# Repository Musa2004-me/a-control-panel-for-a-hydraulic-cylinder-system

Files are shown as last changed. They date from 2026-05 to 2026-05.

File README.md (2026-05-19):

Project Summary 

➢ This project focuses on simulating and operating a control panel for a hydraulic cylinder system. 

➢ The controlling panel manages the extending and retracting a hydraulic piston cylinder with 2 limit switches. 

➢ The primary objective is to understand of the panel's components, their interactions, and the role of hardwiring in its operation. 

https://github.com/user-attachments/assets/3112c67c-48e2-4e45-8f05-624a87322188

https://github.com/user-attachments/assets/3ad71fbe-07a0-4319-b49c-5bb209e37cf8

https://github.com/user-attachments/assets/a876eac6-be53-4f7f-acb0-bc190092581f

Specific Objectives: 
1. Component Identification: identify and understand the function of each 
component, including the hydraulic cylinder, valves, pump, sensors, and 
control logic. 
2. Hardwiring Analysis: Analyse the hardwiring scheme, focusing on the 
connections between components, signal flow, and the role of specific 
wires. 
3. Control Logic Simulation: Simulate the panel's control logic and 
analyse its behaviour. 
4. Real-World Panel Construction: Build a physical control panel that can 
be integrated it with the hydraulic system. 
Within the project we will focus on the components and the automation 
circuit. 
6 
system scenario layout: 
A double-acting cylinder is used to seal jar caps. Once the cylinder completes 
its sealing cycle, an electrical relay is activated to start the conveyor motor, 
moving the next jar into position 
Layout: 
• Conveyor System: Transports jars to the sealing station. 
• Double-acting cylinder: Seals the jar caps. 
• Limit Switch: Detects the completion of the sealing cycle.  
• Electrical Relay: Connects the cylinder's retraction circuit to the conveyor's 
start circuit. 
Description:  
1. Jar Arrival: A jar is positioned under the sealing head. 
2. Cylinder Extension and Sealing: The cylinder extends and seals the jar 
cap. 
3. Cylinder Retraction and Relay Activation: Once the sealing is complete, 
the cylinder retracts, triggering the limit switch. 
4. Conveyor Movement: The activated relay energizes the conveyor motor, 
starting the conveyor and moving the next jar into position. 
5. Cycle Repetition: The process repeats for the next jar.

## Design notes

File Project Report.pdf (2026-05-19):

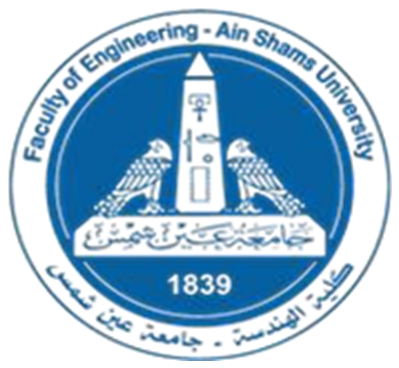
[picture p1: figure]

AIN SHAMS UNIVERSITY-FACULTY OF ENGINEERING

## [MCT312s] Industrial Automation

# Team 1

Submitted to: Dr. Diaa Emad Abdel Fattah Mohamed (https://eng.asu.edu.eg/staff/diaa.emad)

Name | ID | Section
Abdelkarim Wael Abdelkarim | 2101733 | 1 MCT
Mahmoud Salama Mohamed Abdo | 2100961 | 1 MCT
Musa Gamal El-Shenawy | 2100614 | 1 MCT
Abdullah Mahmoud Abdelkarim | 2100658 | 1 MCT
Youssef Ayman | 2002402 | 1 MCT
Sam Isaac | 2002404 | 1 MCT

### Responsibility sheet and task allocation for each team member

NO | Name | Task | Percentage %
1 | Abdelkarim Wael Abdelkarim | -Circuit Design 2D -Purchasing the components -Circuit Connection | 19.5
2 | Mahmoud Salama Mohamed Abdo | -Circuit 3D Modelling -Report -Connection -Labelling | 16
3 | Musa Gamal El-Shenawy | -Report -Purchasing the components -Circuit Connection | 17
4 | Abdullah Mahmoud Abdelkarim | -Circuit 3D Modelling -Purchasing the components -Circuit Connection | 19.5
5 | Youssef Ayman | -Circuit 3D Modelling -Labelling | 14
6 | Sam Isaac | -Circuit 3D Modelling -Labelling | 14

Table of Contents

1

2

### Table of Figures:-

### acronym list

Symbol | Description
NO | Normally Open
NC | Normally Closed
P1(LS1) | Limit switch 1 For Fully Retracted
P2(LS2) | Limit switch 2 For Fully extended

### Introduction

Industrial automation is the application of control systems, like computers and robots, to handle processes and machinery in industrial settings. This technological shift significantly enhances efficiency, accuracy, and productivity in various sectors.
Key Benefits of Industrial Automation:
- Increased Efficiency: Automation reduces labour costs and increases production speed.
- Improved Quality: Consistent product quality and reduced defects.
- Enhanced Safety: Minimizes human error and reduces risks in hazardous environments.
- Optimized Resource Utilization: Maximizes the use of resources like energy and materials.

Industrial automation can be categorized into three primary types:

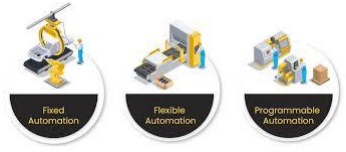
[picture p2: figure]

Programmable Automation: Highly flexible, uses PLCs to control processes.
Flexible Automation: Balances flexibility and efficiency, employs robots and AGVs.
Fixed Automation: Designed for high-volume, repetitive tasks, uses hardwired control systems.

In this project we will focus on hardwired automation:
Hardwiring refers to the physical connection of electronic components using fixed circuits. In the context of automation systems, hardwiring involves using cables and connectors to establish a permanent connection between sensors, actuators, and control units. While hardwiring offers reliability and deterministic performance, it can limit flexibility and scalability. Understanding the intricacies of hardwiring is crucial for designing, implementing, and maintaining automation systems.

### Project Summary

- This project focuses on simulating and operating a control panel for a hydraulic cylinder system.
- The controlling panel manages the extending and retracting a hydraulic piston cylinder with 2 limit switches.
- The primary objective is to understand of the panel's components, their interactions, and the role of hardwiring in its operation.
Specific Objectives:
1. Component Identification: identify and understand the function of each component, including the hydraulic cylinder, valves, pump, sensors, and control logic.
2. Hardwiring Analysis: Analyse the hardwiring scheme, focusing on the connections between components, signal flow, and the role of specific wires.
3. Control Logic Simulation: Simulate the panel's control logic and analyse its behaviour.
4. Real-World Panel Construction: Build a physical control panel that can be integrated it with the hydraulic system.
Within the project we will focus on the components and the automation circuit.

### system scenario layout:

A double-acting cylinder is used to seal jar caps. Once the cylinder completes its sealing cycle, an electrical relay is activated to start the conveyor motor, moving the next jar into position
Layout:
- Conveyor System: Transports jars to the sealing station.
- Double-acting cylinder: Seals the jar caps.
- Limit Switch: Detects the completion of the sealing cycle.
- Electrical Relay: Connects the cylinder's retraction circuit to the conveyor's start circuit.
Description:
1. Jar Arrival: A jar is positioned under the sealing head.
2. Cylinder Extension and Sealing: The cylinder extends and seals the jar cap.
3. Cylinder Retraction and Relay Activation: Once the sealing is complete, the cylinder retracts, triggering the limit switch.
4. Conveyor Movement: The activated relay energizes the conveyor motor, starting the conveyor and moving the next jar into position.
5. Cycle Repetition: The process repeats for the next jar.

### Steps For Electrical Control Panel Manufacturing:-

1) Hardwired Circuit Design and Simulation: -
Design and simulate the electrical circuit to ensure optimal performance and safety.
2) 3D Modelling and Wiring Diagram:-
Develop the 3D model and wiring diagram of the control panel.
3) Component Procurement: -
Determine and purchase the needed components for the control panel.
4) Component and Wire Coding: -
Code the parts and wires for easy assembly and maintenance.
5) Panel Fabrication: -
Manufacture the panel box according to the 3D model to fix the components in it.
6) Component Mounting and Wiring: -
Mount the components and connect them according to the wiring diagram.
7) Labelling: -
Label all components and wires clearly for easy identification and future maintenance.

### Automation circuit :

We used CADE_SIMU To Design and Simulate the Automation Circuit. 1

st industrial circuit

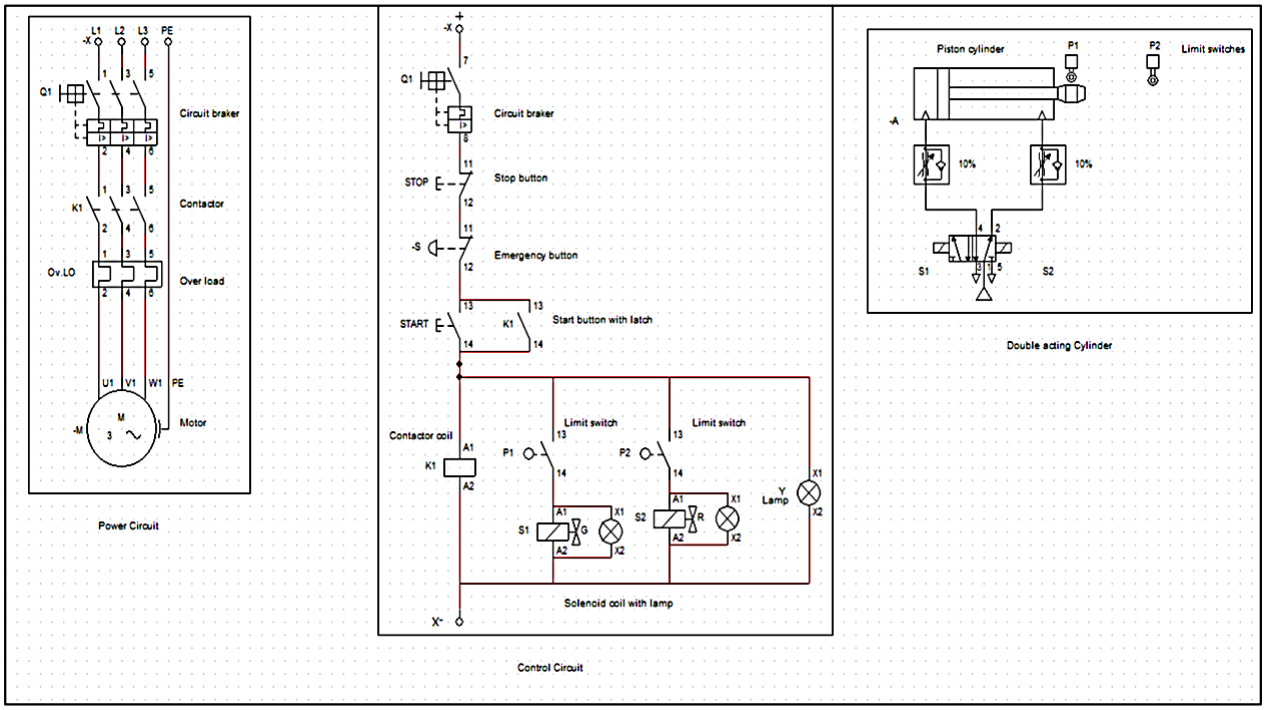
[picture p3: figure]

Figure 1: Industrial Circuit
It’s the full circuit which includes the control panel and the actuators and the hydraulic system.
When the system starts, the motor-driven pump supplies hydraulic fluid to the cylinder, causing it to extend. The extension continues until the cylinder reaches limit switch P2. Upon activation of P2, the 4/2 solenoid valve switches its orientation, reversing the fluid flow. The cylinder then retracts until it reaches limit switch P1 and This cycle repeats continuously.
Drive Link Simulation of the industrial Circuit:-https://drive.google.com/file/d/1AXfAVwLhxbN9mvqJFKnlYuV-bItQRuqS/view?usp=sharing (https://drive.google.com/file/d/1AXfAVwLhxbN9mvqJFKnlYuV-bItQRuqS/view?usp=sharing)
The industrial circuit is divided into 3 circuits:

1- Power Circuit
2- Control Circuit
3- Hydraulic Circuit

Industrial Power circuit.
The A power circuit is essential for supplying electrical energy to the control panel and ensures the safety of the system, it may use 3 phases or single-phase power depending on the power regulations of the components. It consists of:
- Circuit Breaker: Protects the circuit from overcurrent and short circuits.
- Contactor: A type of relay that switches large electrical loads, such as the motor driving the hydraulic pump.
- Thermal overload relay :serves as a
crucial protective device in electrical

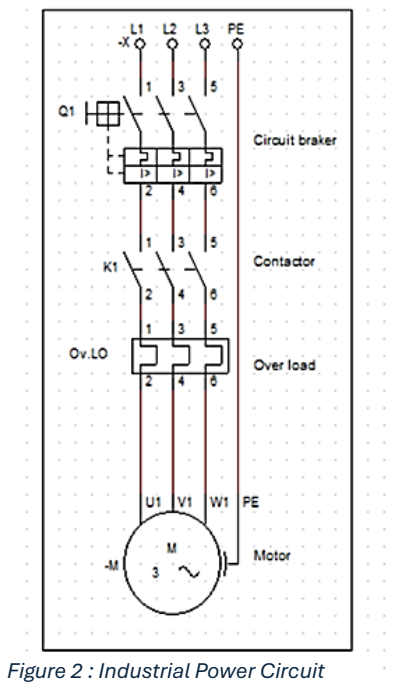
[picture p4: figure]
Figure 2 : Industrial Power Circuit

systems, primarily used to safeguard motors from overheating and potential damage due to excessive current. It operates based on the principle of thermal sensing, monitoring the heat generated by the motor during operation.

- Hydraulic Pump Motor: Converts electrical energy into mechanical energy to drive the hydraulic pump.

Industrial Control circuit:
A control circuit is the brains behind a hydraulic cylinder system, responsible for interpreting input signals and generating output signals to control the cylinder's movement. usually, it works on a single-phase power supply.
It consists of:
- Circuit Breaker: Protects the circuit from overcurrent and short circuits.
- Stop button: to stop the system.
- Emergency button: to manually stop the system in case of errors or emergency.
- Start with latch: button to start
the system operation and it latches

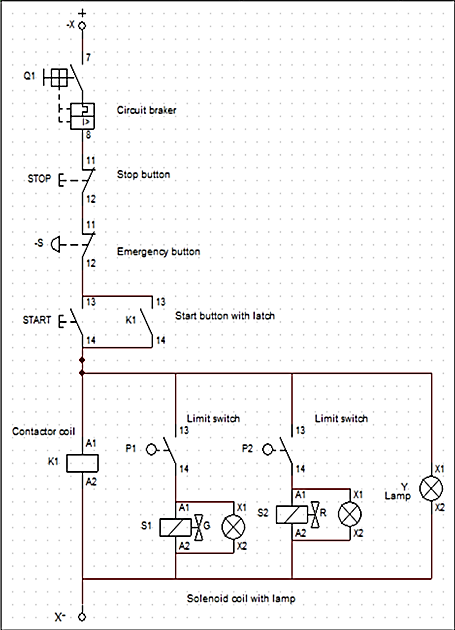
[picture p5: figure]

using the conductor normally opened switch.
- Limit switches: Limit switches are electromechanical devices that detect the position of a moving object.

Figure 3: Industrial Control Circuit

hydraulic circuit:
A double-acting cylinder circuit is a common hydraulic system that utilizes a hydraulic cylinder capable of extending and retracting under fluid pressure. A 4/2 directional control valve is typically used to control the fluid flow to the cylinder's ports, enabling bidirectional movement.
It consists of:
- 4/2cDirectional Control Valve:
Controls the flow of hydraulic fluid

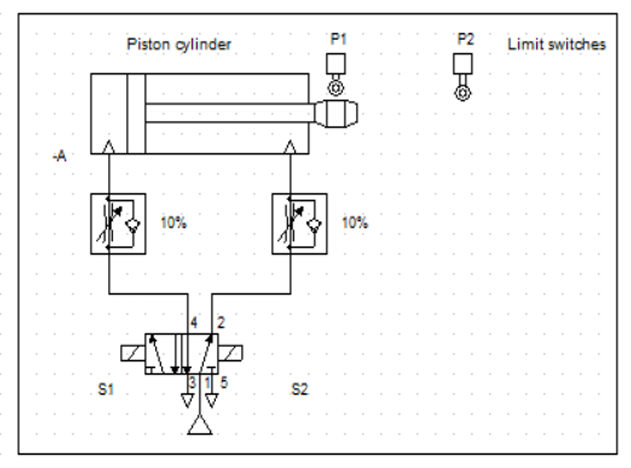
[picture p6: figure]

to the cylinder's ports, determining its direction of movement. (controlled by solenoid s1)
- Double-Acting Cylinder: Converts hydraulic energy into mechanical work.
- Flow Control Valve: Regulates the flow rate of hydraulic fluid to the cylinder.
- Limit switches: Limit switches are electromechanical devices that detect the position of a moving object.

Figure 4:l Hydraulic Circuit nd Control Panel Model Circuit

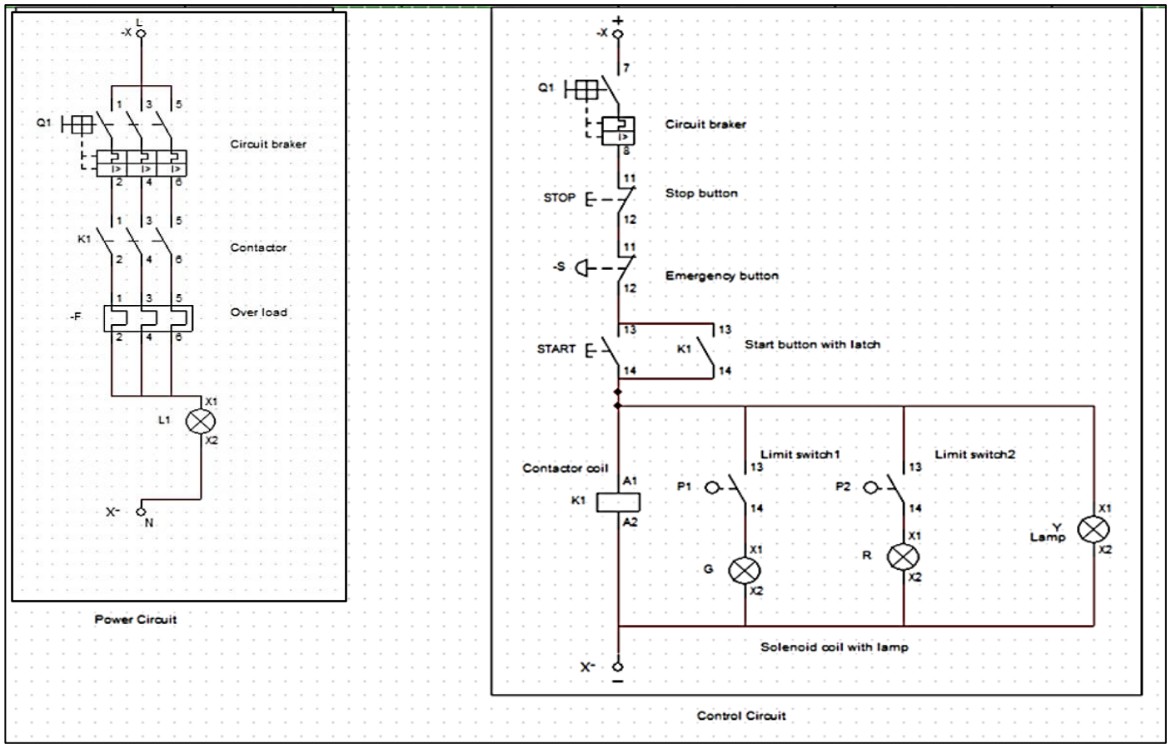
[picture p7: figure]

Figure 5: Control Panel Circuit
It’s the simulated model of the industrial control panel which uses lamps as indicators instead of using actuators.
circuit description
when start button pressed it operates contactor relay k1 which latches the start button and connect electricity to the system , when limit switch p1 is pressed it indicates the cylinder is fully retracted and operates green lamp , when limit switch p2 is pressed it indicates the cylinder is fully extended operates red lamp , the yellow lamp indicates that the system is operating The control panel circuit is divided into 2 circuits:
1-Power Circuit
2-Control Circuit

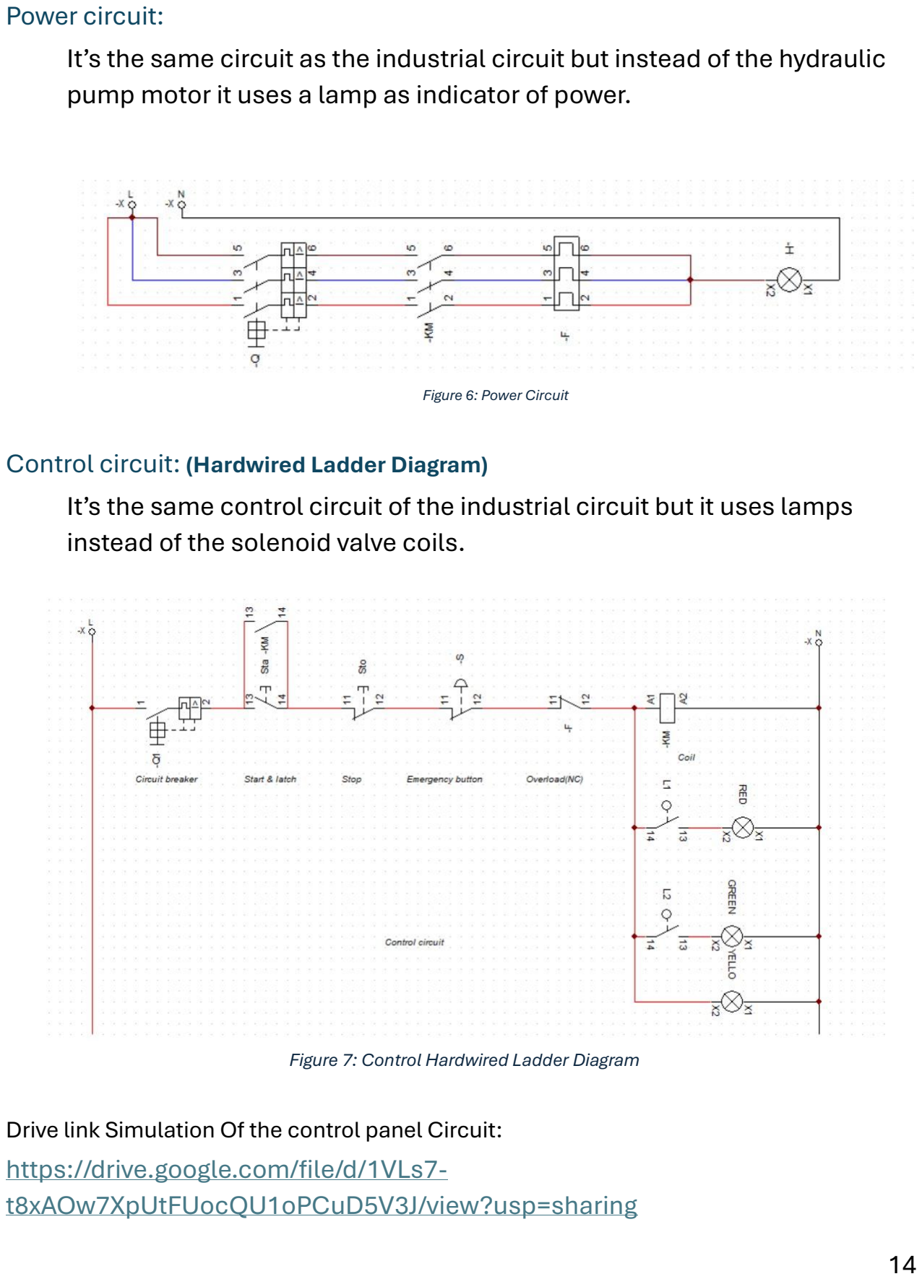
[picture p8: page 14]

Power circuit:
It’s the same circuit as the industrial circuit but instead of the hydraulic pump motor it uses a lamp as indicator of power.

Control circuit: (Hardwired Ladder Diagram)
It’s the same control circuit of the industrial circuit but it uses lamps instead of the solenoid valve coils.

Drive link Simulation Of the control panel Circuit: https://drive.google.com/file/d/1VLs7-t8xAOw7XpUtFUocQU1oPCuD5V3J/view?usp=sharing (https://drive.google.com/file/d/1VLs7-t8xAOw7XpUtFUocQU1oPCuD5V3J/view?usp=sharing)

Figure 6: Power Circuit

Figure 7: Control Hardwired Ladder Diagram

### 3D Model and Wiring Diagram:-

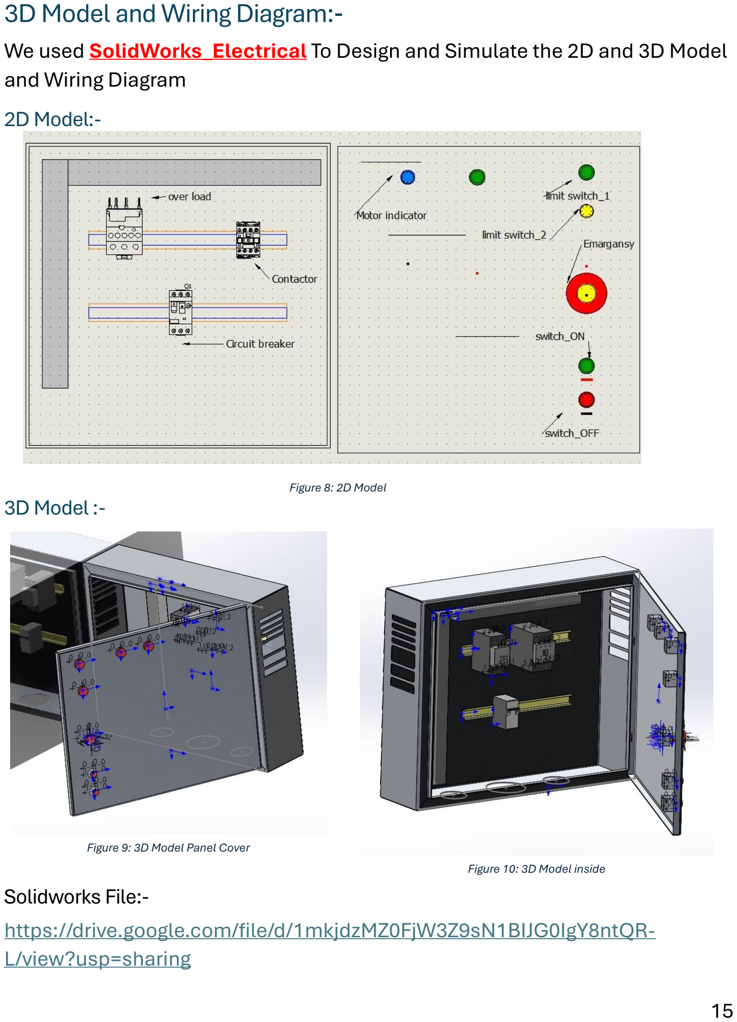
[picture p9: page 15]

We used SolidWorks_Electrical To Design and Simulate the 2D and 3D Model and Wiring Diagram
2D Model:-

3D Model :-

Solidworks File:-
https://drive.google.com/file/d/1mkjdzMZ0FjW3Z9sN1BIJG0IgY8ntQR-L/view?usp=sharing (https://drive.google.com/file/d/1mkjdzMZ0FjW3Z9sN1BIJG0IgY8ntQR-L/view?usp=sharing)

Figure 8: 2D Model

Figure 10: 3D Model inside

Figure 9: 3D Model Panel Cover

### List of Component

No | Name | Role | characteristics | Photo
1 | Circuit Breaker | for power circuit to protect all circuit components from over current | 3phase 340 v 16 A

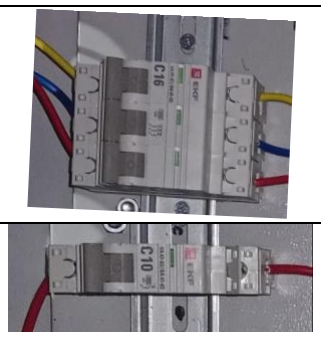
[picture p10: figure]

2 | Circuit Breaker | for control circuit to protect circuit components from over current | 1 phase 220-240 v 10 A

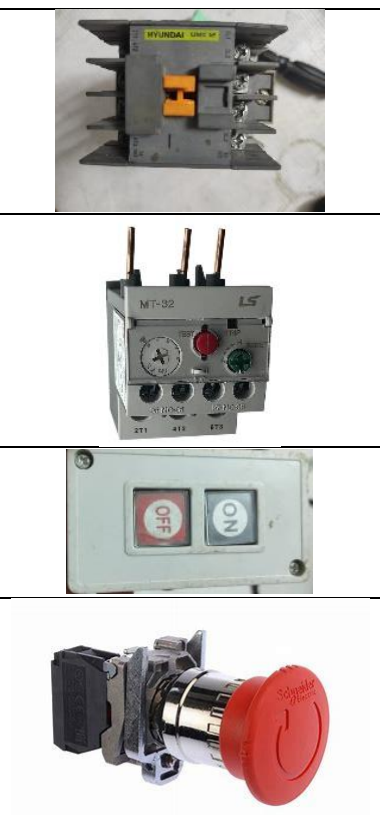
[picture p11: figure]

3 | Contactor | it used to control motor on/off by using coil and NO contact points | 3phase 200-460 v 16 A
4 | Overload Relay M32 https://kentstore.com/content/pdf/MT-32_specs.pdf (https://kentstore.com/content/pdf/MT-32_specs.pdf) | to protect motor from over current by heat generated and bimetallic switch | 3phase 340 v 16 A
5 | ON,OFF Push buttons | Two switch on and off turn on system or turn off | 1 phase 220-240 v 3A
6 | Emergency Stop Button | The function of an emergency stop button is to act as a safety mechanism (https://www.bing.com/ck/a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) it stops all functions immediately when it cannot be shut down manually by a user. (https://www.bing.com/ck/a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) | 220-240 v 3A

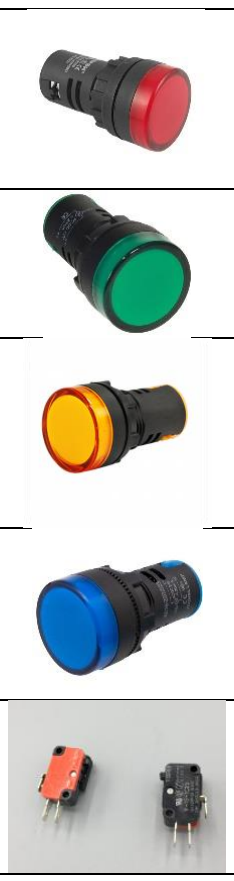
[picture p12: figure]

7 | Red LED | an indication that piston is fully retracted | 220-240 v
8 | Green LED | an indication that piston is fully extended | 220-240 v
9 | Yellow LED | an indication that control circuit is working | 220-240 v
10 | Blue LED | an indication that the motor is work | 220-240 v
11 | Limit Switch LS1, LS2 | to control the limits of Expanding and Retracting of the Cylinder | 220-240 v 5A
12 | Electrical Panel box , Duct and Wires

### Wiring Selection:-

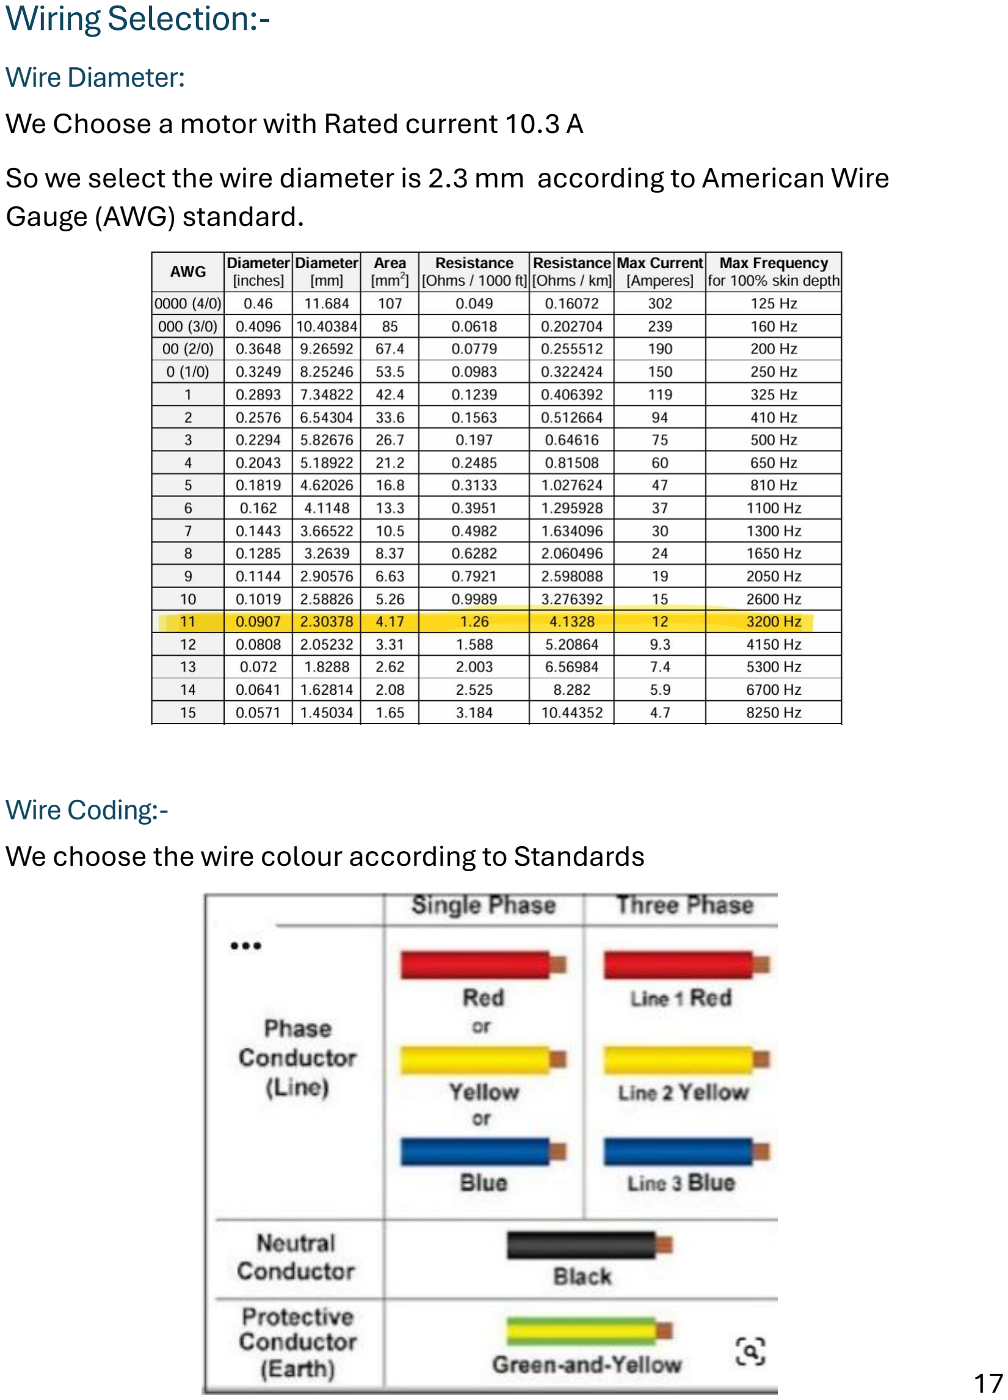
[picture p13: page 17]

Wire Diameter:
We Choose a motor with Rated current 10.3 A
So we select the wire diameter is 2.3 mm according to American Wire Gauge (AWG) standard.

Wire Coding:-
We choose the wire colour according to Standards

### Implementation Control Panel:-

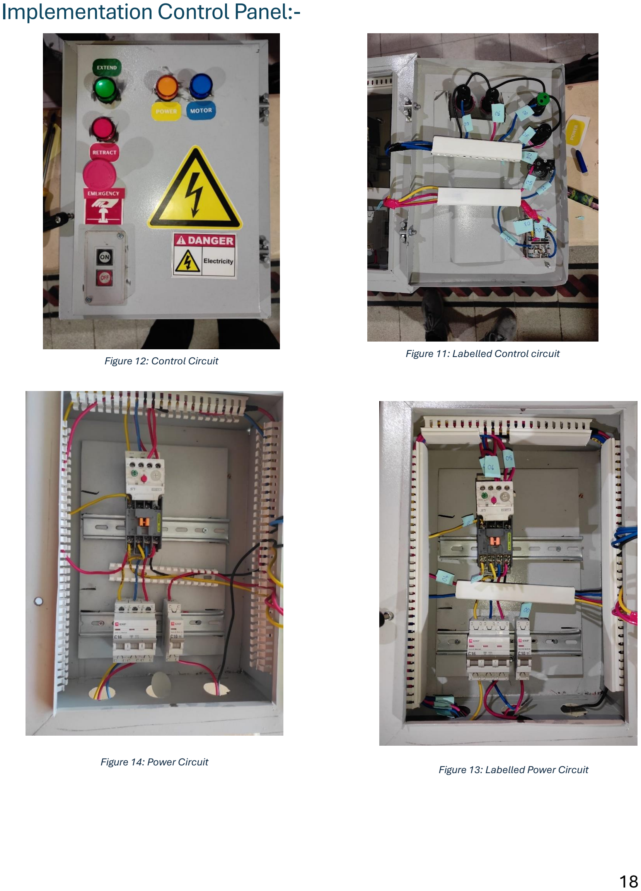
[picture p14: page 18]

Figure 12: Control Circuit

Figure 11: Labelled Control circuit

Figure 14: Power Circuit
Figure 13: Labelled Power Circuit

### Labelling:

label | Description
00 | ON-Circuit Breaker
01 | Off-Emergency
02 | ON-NO contacter
03 | ON- NO contactor
04 | Limit switch- NC overload relay
05 | Emergency- NC overload relay
06 | Emergency - Yellow Led
07 | Limit switch - Red Led
08 | Limit switch - Green Led
09 | Overload relay- Blue led

### Testing :-

https://drive.google.com/file/d/10U3l7anMuX0P6ioPTWcRQP9o1-E0bxOd/view?usp=sharing (https://drive.google.com/file/d/10U3l7anMuX0P6ioPTWcRQP9o1-E0bxOd/view?usp=sharing)

### Reference:-

- American Wire Gauge (AWG) standard.
- The NEC wire colour coding standards.

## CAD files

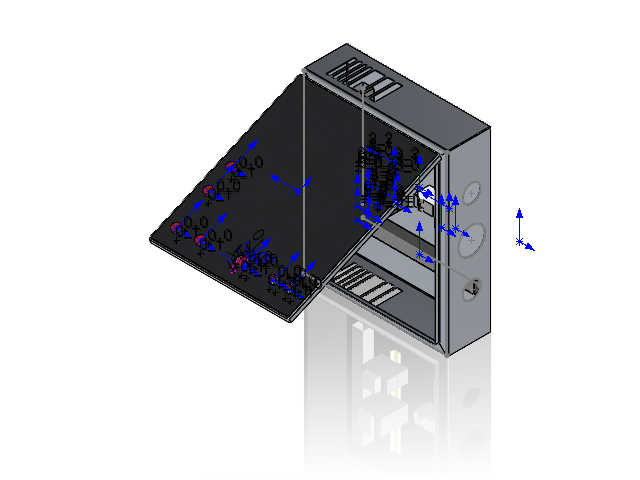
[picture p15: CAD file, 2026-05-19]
Solid-works.SLDASM
Electrical wirebox
EW_RAIL_V x 2
EW_DUCT_H1
EW_DUCT_H2
EW_DUCT_V1
EW_DUCT_V2
EW_DOOR_BUTTON x 2
EW_RELAY_POWER
EW_DOOR_EMERGENCY_55
EW_DOOR_INDICATOR x 4
EW_RELAY_FUNCTION
EW_CIRCUIT_BREAKER_35

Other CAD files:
ANSI_3/ANSI_3/1/13.dwg
ANSI_3/ANSI_3/1/2.dwg
ANSI_3/ANSI_3/1/1.dwg
ANSI_3/ANSI_3/1/4.dwg
ANSI_3/ANSI_3/1/3.dwg
ANSI_3/ANSI_3/1/15.dwg
ANSI_3/ANSI_3/1/14.dwg
ANSI_3/ANSI_3/1/5.dwg
ANSI_3/ANSI_3/1/16.dwg
